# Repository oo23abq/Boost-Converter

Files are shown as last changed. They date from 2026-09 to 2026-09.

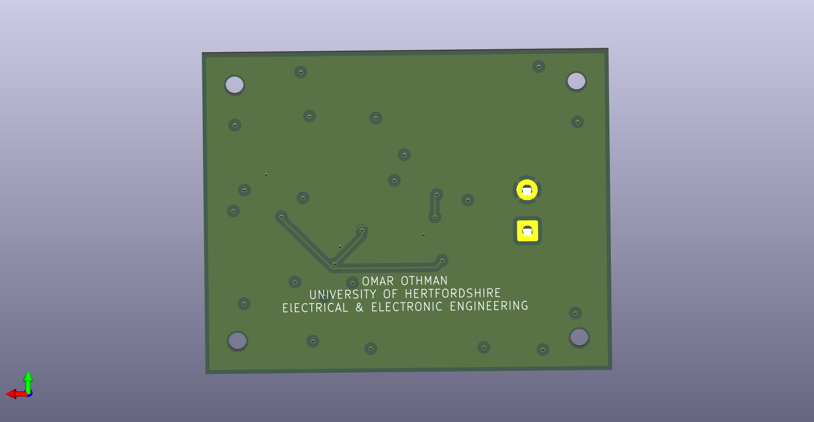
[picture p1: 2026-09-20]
kicad/images/boostconverter_bottom.png

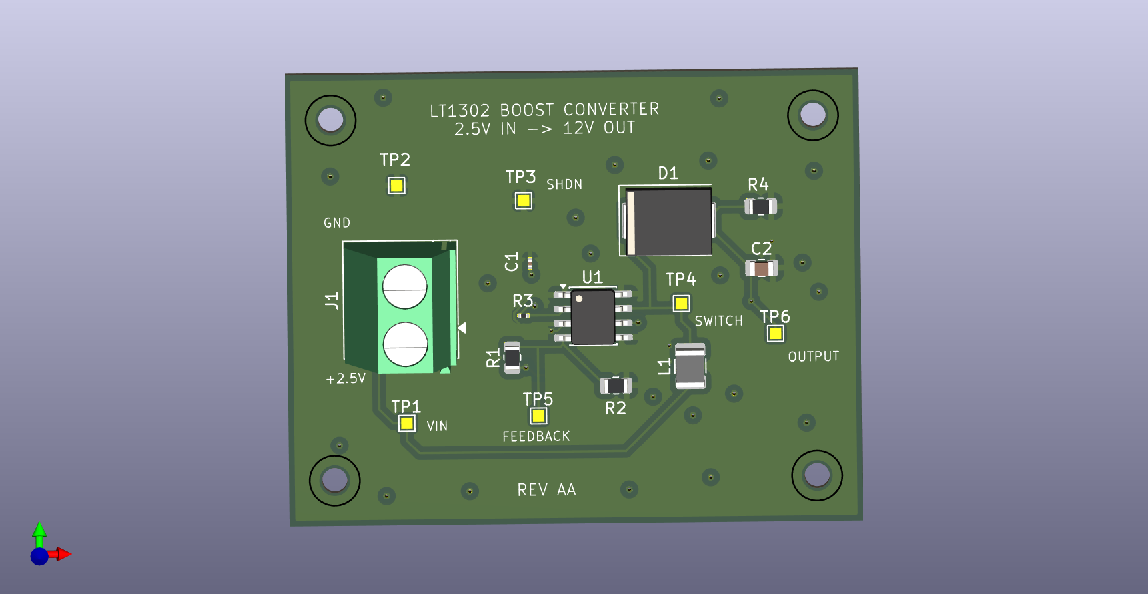
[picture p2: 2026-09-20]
kicad/images/boostconverter_top.png

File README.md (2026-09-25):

# Boost-Converter-PCB
simple design of a boost converter PCB in kicad

## Repository Structure

```markdown

```text
├── docs/                               # General Documentation  
│   └── testreport.txt                  # Lab Test Report  
├── kicad/                              # KiCAD Project Files 
│   ├── Boost Converter.kicad_pcb       # PCB Board File
│   ├── Boost Converter.kicad_sch       # Schematic File 
│   ├── bom.csv                         # Bill of Materials
│   ├── gerbers/                        # Manufacturing Files 
│   │   └── boost.zip                   # Gerber and NC Drill Archives 
│   └── images/                         # 3D Renders 
│       ├── boostconverter_bottom.png   # Bottom Layer 
│       └── boostconverter_top.png      # Top Layer 
├── ltspice/                            # Analogue Simulation 
│   ├── schematic.asc                   # LTspice Schematic
│   └── waveform.asc                    # Plot pane waveform
├── testing/                            # Lab Testing
│   ├── oscilloscopeinput.png           # Input Voltage Waveform  
│   ├── oscilloscopeoutput.png          # Output Voltage Transient Response
│   └── testsetup.png                   # Bench test setup 
├── LICENSE                             # MIT License File 
└── README.md                           # Project Guidance / Info

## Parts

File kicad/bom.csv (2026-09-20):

Reference | Qty | Value | DNP | Exclude from BOM | Exclude from Board | Footprint | Datasheet
C1 | 1 | 0.01µ |  |  |  | Capacitor_SMD:C_0201_0603Metric
C2 | 1 | 100µ |  |  |  | Capacitor_SMD:C_0805_2012Metric
D1 | 1 | MBRS340 |  |  |  | Diode_SMD:ST_D_SMC
J1 | 1 | Conn_01x02_Pin |  |  |  | TerminalBlock_Phoenix:TerminalBlock_Phoenix_MKDS-1,5-2-5.08_1x02_P5.08mm_Horizontal | ~
L1 | 1 | 3.3µ |  |  |  | Inductor_SMD:L_1210_3225Metric
R1 | 1 | 86.6k |  |  |  | Resistor_SMD:R_0805_2012Metric
R2 | 1 | 10k |  |  |  | Resistor_SMD:R_0805_2012Metric
R3 | 1 | 20K |  |  |  | Resistor_SMD:R_0201_0603Metric
R4 | 1 | 240 |  |  |  | Resistor_SMD:R_0805_2012Metric
TP1,TP2,TP3,TP4,TP5,TP6 | 6 | TestPoint |  |  |  | TestPoint:TestPoint_Pad_1.0x1.0mm | ~
U1 | 1 | LT1302 |  |  |  | Package_SO:SOIC-8-1EP_3.9x4.9mm_P1.27mm_EP2.29x3mm

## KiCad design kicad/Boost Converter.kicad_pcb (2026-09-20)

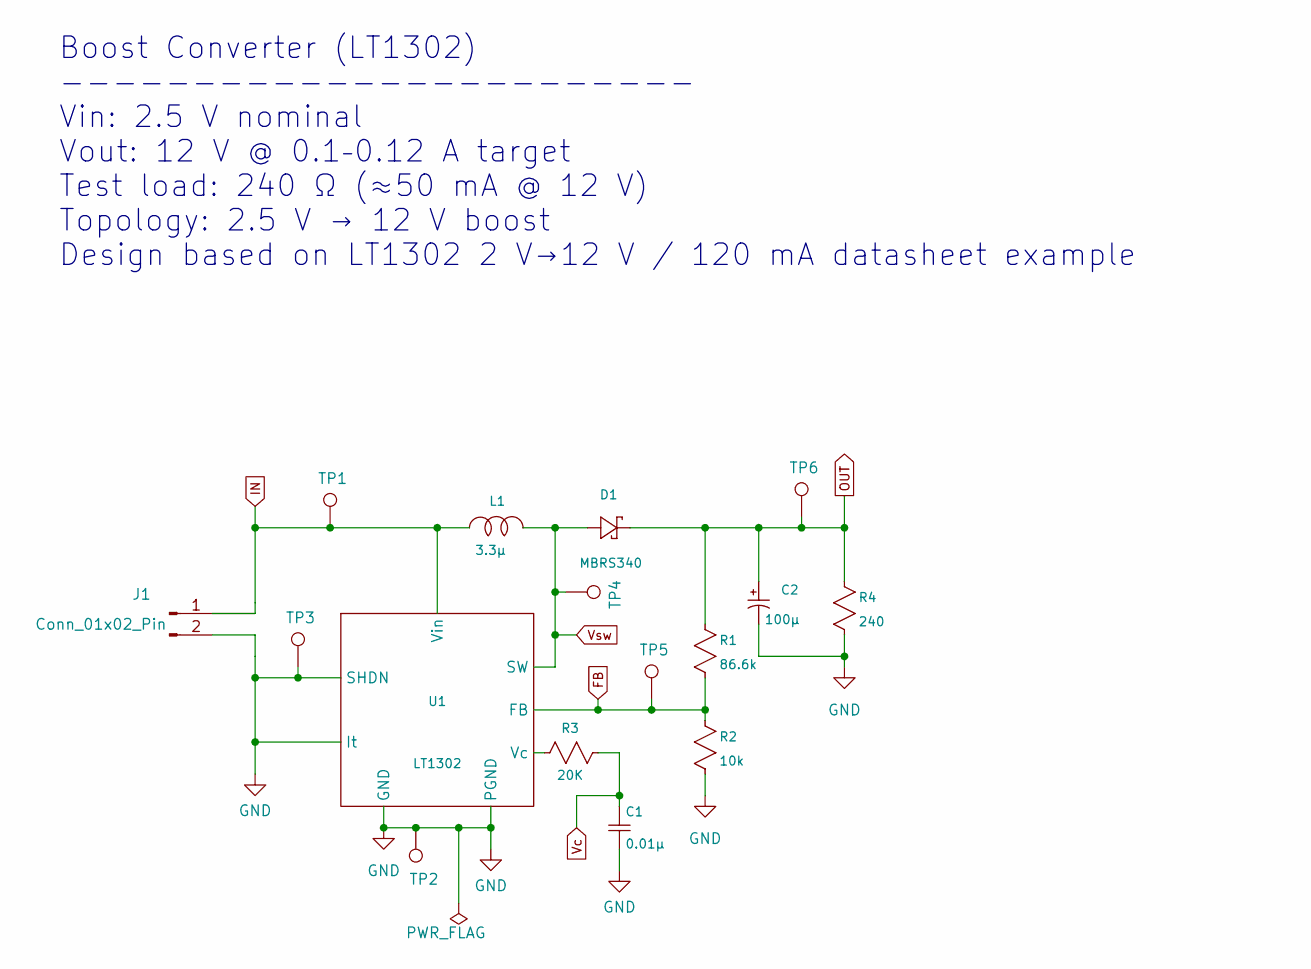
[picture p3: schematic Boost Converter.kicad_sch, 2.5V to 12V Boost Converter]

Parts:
C1: 0.01µ; C_0201_0603Metric
C2: 100µ; C_0805_2012Metric
D1: MBRS340; ST_D_SMC
J1: Conn_01x02_Pin; TerminalBlock_Phoenix_MKDS-1,5-2-5.08_1x02_P5.08mm_Horizont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
L1: 3.3µ; L_1210_3225Metric
R1: 86.6k; R_0805_2012Metric
R2: 10k; R_0805_2012Metric
R3: 20K; R_0201_0603Metric
R4: 240; R_0805_2012Metric
TP1, TP2, TP3, TP4, TP5, TP6: TestPoint; TestPoint_Pad_1.0x1.0mm
U1: LT1302; SOIC-8-1EP_3.9x4.9mm_P1.27mm_EP2.29x3mm

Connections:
FB: R1.2, R2.1, TP5.1, U1.4 (FB)
GND: C1.2, C2.2 (B), J1.2, R2.2, R4.2, TP2.1, TP3.1, U1.1 (GND), U1.3 (SHDN), U1.5 (It), U1.8 (PGND)
IN: J1.1, L1.1, TP1.1, U1.6 (Vin)
unnamed: R3.1, U1.2 (Vc)
OUT: C2.1 (A), D1.2 (-), R1.1, R4.1, TP6.1
Vc: C1.1, R3.2
Vsw: D1.1 (+), L1.2, TP4.1, U1.7 (SW)

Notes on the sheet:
Boost Converter (LT1302) ------------------------ Vin: 2.5 V nominal Vout: 12 V @ 0.1–0.12 A target Test load: 240 Ω (≈50 mA @ 12 V) Topology: 2.5 V → 12 V boost Design based on LT1302 2 V→12 V / 120 mA datasheet example

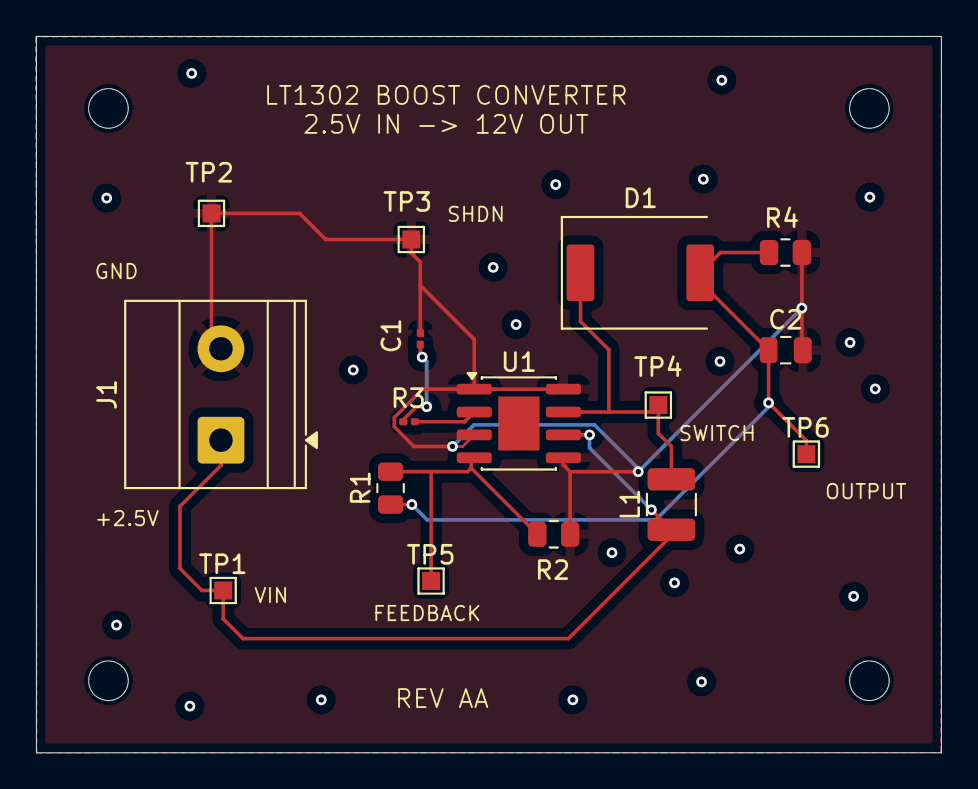
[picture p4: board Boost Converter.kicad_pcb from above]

Board: 2 copper layers, 50.3 x 39.8 mm, 20 parts (0 on the bottom side), 7 nets.

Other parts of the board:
MH1, MH2, MH3, MH4: MountingHole_2.2mm_M2
